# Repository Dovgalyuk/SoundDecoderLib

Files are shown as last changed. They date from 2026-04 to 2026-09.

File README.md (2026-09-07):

# Maple RailRoad Sound Decoder

WiFi controller, sound decoder, and sound projects for model trains.

Project includes library for programming the sounds with set of state machines.

There are several ready-to-use sample sound projects.

Web interface for locomotive operation

Render of the PCB

# Project structure

* esp32 - directory where building of the firmware starts
* hardware - several versions of PCBs for manufacturing the decoder
* projects - ready-to-use sound projects for different locomotives
* compiler - compiler for the sound projects
* emulator - cab emulator for listening sounds with virtual locomotive control
* sample - dummy player which generates wav file by interpreting the sound project
* other directories include the source code of the firmware

# Bringing locomotive to life

* Get the hardware (order PCB, solder the components)
* Build firmware
  * Install ESP32 toolkit (esp idf)
  * Run esp32/build32M.sh (or other version)
* Upload esp32/build32M/esp32sounddecoder.bin into the ESP32 module
* Build selected sound project with compiler/compiler.py
* Upload built project through the web interface into the controller
* Install the controller into the locomotive

# Software features

Controller provides web interface that may be accessed through
WiFi (default address 192.168.4.1).

Sound module plays 8- or 16-bit sounds in 8 channels.

Output functions and sound schemes are programmed with
custom language. The scripts may include conditions,
loops, and finite state machines. These features
may be used for creating complex sound projects.

# Hardware

Controller is intended to be used with G-scale locomotives
with lithium batteries installed, but it may also be used
with track power (some power capacitors are probably needed).

Controller includes the following hardware components:
* ESP32 CPU with embedded WiFi module and flash memory
* Motor driver
* I2S audio power amplifier (MAX98357A)
* 7 programmable outputs
* BEMF for adjusting the motor speed (work in progress)

# Roadmap

* BEMF with new motor driver
* Support of logical input/outputs
* H0-compatible PCB

# Links

* Radio-controlled engines with sound
  - https://github.com/TheDIYGuy999/Rc_Engine_Sound_ESP32
* Cost effective DIY DCC Decoder for model railroad locomotives
  - https://github.com/gab-k/RP2040-Decoder
* NIMRS: open-source NIMRS-21Pin-Decoder, based on the ESP32-S3 microcontroller
  - https://github.com/CDFER/NIMRS-21Pin-Decoder
  - https://github.com/ProjectInitiative/NIMRS-Firmware

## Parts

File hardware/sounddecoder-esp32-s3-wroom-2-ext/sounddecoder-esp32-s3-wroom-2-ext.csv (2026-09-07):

Reference | Qty | Value | DNP | Exclude from BOM | Exclude from Board | Footprint | Datasheet
C1,C3,C8,C10 | 4 | 0.1uF |  |  |  | Capacitor_SMD:C_0805_2012Metric_Pad1.18x1.45mm_HandSolder | ~
C2 | 1 | 47uF |  |  |  | Capacitor_SMD:CP_Elec_6.3x5.4 | ~
C4 | 1 | 470uF |  |  |  | Capacitor_SMD:CP_Elec_10x10.5 | ~
C5 | 1 | 220uF |  |  |  | Capacitor_SMD:C_Elec_6.3x7.7 | ~
C6 | 1 | 22uF |  |  |  | Capacitor_SMD:CP_Elec_4x5.4 | ~
C7 | 1 | 10uF |  |  |  | Capacitor_SMD:C_0805_2012Metric_Pad1.18x1.45mm_HandSolder | ~
C11 | 1 | 22uF |  |  |  | Capacitor_SMD:C_0805_2012Metric_Pad1.18x1.45mm_HandSolder | ~
C12 | 1 | 1uF |  |  |  | Capacitor_SMD:C_0805_2012Metric_Pad1.18x1.45mm_HandSolder | ~
D1 | 1 | SS54 |  |  |  | Diode_SMD:D_SMC | http://www.vishay.com/docs/88526/1n5820.pdf
J1 | 1 | Input power |  |  |  | TerminalBlock:TerminalBlock_Xinya_XY308-2.54-2P_1x02_P2.54mm_Horizontal | ~
J2 | 1 | Extension |  |  |  | Connector_PinHeader_1.27mm:PinHeader_2x08_P1.27mm_Vertical_SMD | ~
J3 | 1 | Motor |  |  |  | TerminalBlock:TerminalBlock_Xinya_XY308-2.54-2P_1x02_P2.54mm_Horizontal | ~
J4 | 1 | Speaker |  |  |  | TerminalBlock:TerminalBlock_Xinya_XY308-2.54-2P_1x02_P2.54mm_Horizontal | ~
J6 | 1 | Conn_01x03_Pin |  |  |  | Connector_PinHeader_1.00mm:PinHeader_1x03_P1.00mm_Vertical | ~
J7 | 1 | Smoke |  |  |  | TerminalBlock:TerminalBlock_Xinya_XY308-2.54-2P_1x02_P2.54mm_Horizontal | ~
J8 | 1 | FwdLED |  |  |  | TerminalBlock:TerminalBlock_Xinya_XY308-2.54-2P_1x02_P2.54mm_Horizontal | ~
J9 | 1 | BackLED |  |  |  | TerminalBlock:TerminalBlock_Xinya_XY308-2.54-2P_1x02_P2.54mm_Horizontal | ~
J10 | 1 | AUX1 |  |  |  | TerminalBlock:TerminalBlock_Xinya_XY308-2.54-2P_1x02_P2.54mm_Horizontal | ~
J11 | 1 | AUX2 |  |  |  | TerminalBlock:TerminalBlock_Xinya_XY308-2.54-2P_1x02_P2.54mm_Horizontal | ~
J12 | 1 | AUX3 |  |  |  | TerminalBlock:TerminalBlock_Xinya_XY308-2.54-2P_1x02_P2.54mm_Horizontal | ~
J13 | 1 | AUX4 |  |  |  | TerminalBlock:TerminalBlock_Xinya_XY308-2.54-2P_1x02_P2.54mm_Horizontal | ~
L1 | 1 | 47uh/L39 |  |  |  | Inductor_SMD:L_Bourns_SRP1245A | ~
R1,R6,R7 | 3 | 1k |  |  |  | Resistor_SMD:R_0805_2012Metric_Pad1.20x1.40mm_HandSolder | ~
R2,R3 | 2 | 10k |  |  |  | Resistor_SMD:R_0805_2012Metric_Pad1.20x1.40mm_HandSolder | ~
R4,R5 | 2 | 20k |  |  |  | Resistor_SMD:R_0805_2012Metric_Pad1.20x1.40mm_HandSolder | ~
U1 | 1 | LM2596S-5 |  |  |  | Package_TO_SOT_SMD:TO-263-5_TabPin3 | http://www.ti.com/lit/ds/symlink/lm2596.pdf
U3 | 1 | MAX98357A |  |  |  | Package_DFN_QFN:TQFN-16-1EP_3x3mm_P0.5mm_EP1.23x1.23mm | https://www.analog.com/media/en/technical-documentation/data-sheets/MAX98357A-MAX98357B.pdf
U4 | 1 | DRV8251A |  |  |  | Package_SO:Texas_HSOP-8-1EP_3.9x4.9mm_P1.27mm_ThermalVias
U6 | 1 | AMS1117-3.3 |  |  |  | Package_TO_SOT_SMD:SOT-223-3_TabPin2 | http://www.advanced-monolithic.com/pdf/ds1117.pdf
U7 | 1 | ESP32-S3-WROOM-2 |  |  |  | RF_Module:ESP32-S3-WROOM-2 | https://www.espressif.com/sites/default/files/documentation/esp32-s3-wroom-2_datasheet_en.pdf
U8 | 1 | ULN2003A |  |  |  | Package_SO:SO-16_3.9x9.9mm_P1.27mm | http://www.ti.com/lit/ds/symlink/uln2003a.pdf

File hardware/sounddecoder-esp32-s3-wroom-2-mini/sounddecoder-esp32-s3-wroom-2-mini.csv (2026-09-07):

Reference | Qty | Value | DNP | Exclude from BOM | Exclude from Board | Footprint | Datasheet
C1,C3,C8,C10 | 4 | 0.1uF |  |  |  | Capacitor_SMD:C_0805_2012Metric | ~
C4 | 1 | 470uF |  |  |  | Capacitor_SMD:CP_Elec_10x10.5 | ~
C5 | 1 | 220uF |  |  |  | Capacitor_SMD:C_Elec_6.3x7.7 | ~
C6 | 1 | 22uF |  |  |  | Capacitor_SMD:CP_Elec_4x5.4 | ~
C7 | 1 | 10uF |  |  |  | Capacitor_SMD:C_0805_2012Metric | ~
C11 | 1 | 22uF |  |  |  | Capacitor_SMD:C_0805_2012Metric | ~
C12 | 1 | 1uF |  |  |  | Capacitor_SMD:C_0805_2012Metric | ~
D1 | 1 | SS54 |  |  |  | Diode_SMD:D_SMC | http://www.vishay.com/docs/88526/1n5820.pdf
J1 | 1 | Input power |  |  |  | TerminalBlock:TerminalBlock_Xinya_XY308-2.54-2P_1x02_P2.54mm_Horizontal | ~
J2 | 1 | Conn_01x02_Pin |  |  |  | Connector_PinHeader_1.00mm:PinHeader_1x02_P1.00mm_Vertical | ~
J3 | 1 | Motor |  |  |  | TerminalBlock:TerminalBlock_Xinya_XY308-2.54-2P_1x02_P2.54mm_Horizontal | ~
J4 | 1 | Speaker |  |  |  | Connector_PinHeader_2.54mm:PinHeader_1x02_P2.54mm_Vertical | ~
J8 | 1 | FwdLED |  |  |  | Connector_PinHeader_2.54mm:PinHeader_1x02_P2.54mm_Vertical | ~
J9 | 1 | BackLED |  |  |  | Connector_PinHeader_2.54mm:PinHeader_1x02_P2.54mm_Vertical | ~
J10 | 1 | AUX1 |  |  |  | Connector_PinHeader_2.54mm:PinHeader_1x02_P2.54mm_Vertical | ~
J11 | 1 | AUX2 |  |  |  | Connector_PinHeader_2.54mm:PinHeader_1x02_P2.54mm_Vertical | ~
J101 | 1 | Conn_01x05 |  |  |  | Connector_PinHeader_2.54mm:PinHeader_1x05_P2.54mm_Vertical | ~
L1 | 1 | 47uh/L39 |  |  |  | Inductor_SMD:L_Bourns_SRP1245A | ~
R1,R6,R7 | 3 | 1k |  |  |  | Resistor_SMD:R_0805_2012Metric | ~
R2,R3 | 2 | 10k |  |  |  | Resistor_SMD:R_0805_2012Metric | ~
R4,R5 | 2 | 20k |  |  |  | Resistor_SMD:R_0805_2012Metric | ~
U1 | 1 | LM2596S-5 |  |  |  | Package_TO_SOT_SMD:TO-263-5_TabPin3 | http://www.ti.com/lit/ds/symlink/lm2596.pdf
U3 | 1 | MAX98357A |  |  |  | Package_DFN_QFN:TQFN-16-1EP_3x3mm_P0.5mm_EP1.23x1.23mm | https://www.analog.com/media/en/technical-documentation/data-sheets/MAX98357A-MAX98357B.pdf
U4 | 1 | DRV8251A |  |  |  | Package_SO:Texas_HSOP-8-1EP_3.9x4.9mm_P1.27mm_ThermalVias
U6 | 1 | AMS1117-3.3 |  |  |  | Package_TO_SOT_SMD:SOT-223-3_TabPin2 | http://www.advanced-monolithic.com/pdf/ds1117.pdf
U7 | 1 | ESP32-S3-WROOM-2 |  |  |  | RF_Module:ESP32-S3-WROOM-2 | https://www.espressif.com/sites/default/files/documentation/esp32-s3-wroom-2_datasheet_en.pdf
U8 | 1 | ULN2003A |  |  |  | Package_SO:SO-16_3.9x9.9mm_P1.27mm | http://www.ti.com/lit/ds/symlink/uln2003a.pdf

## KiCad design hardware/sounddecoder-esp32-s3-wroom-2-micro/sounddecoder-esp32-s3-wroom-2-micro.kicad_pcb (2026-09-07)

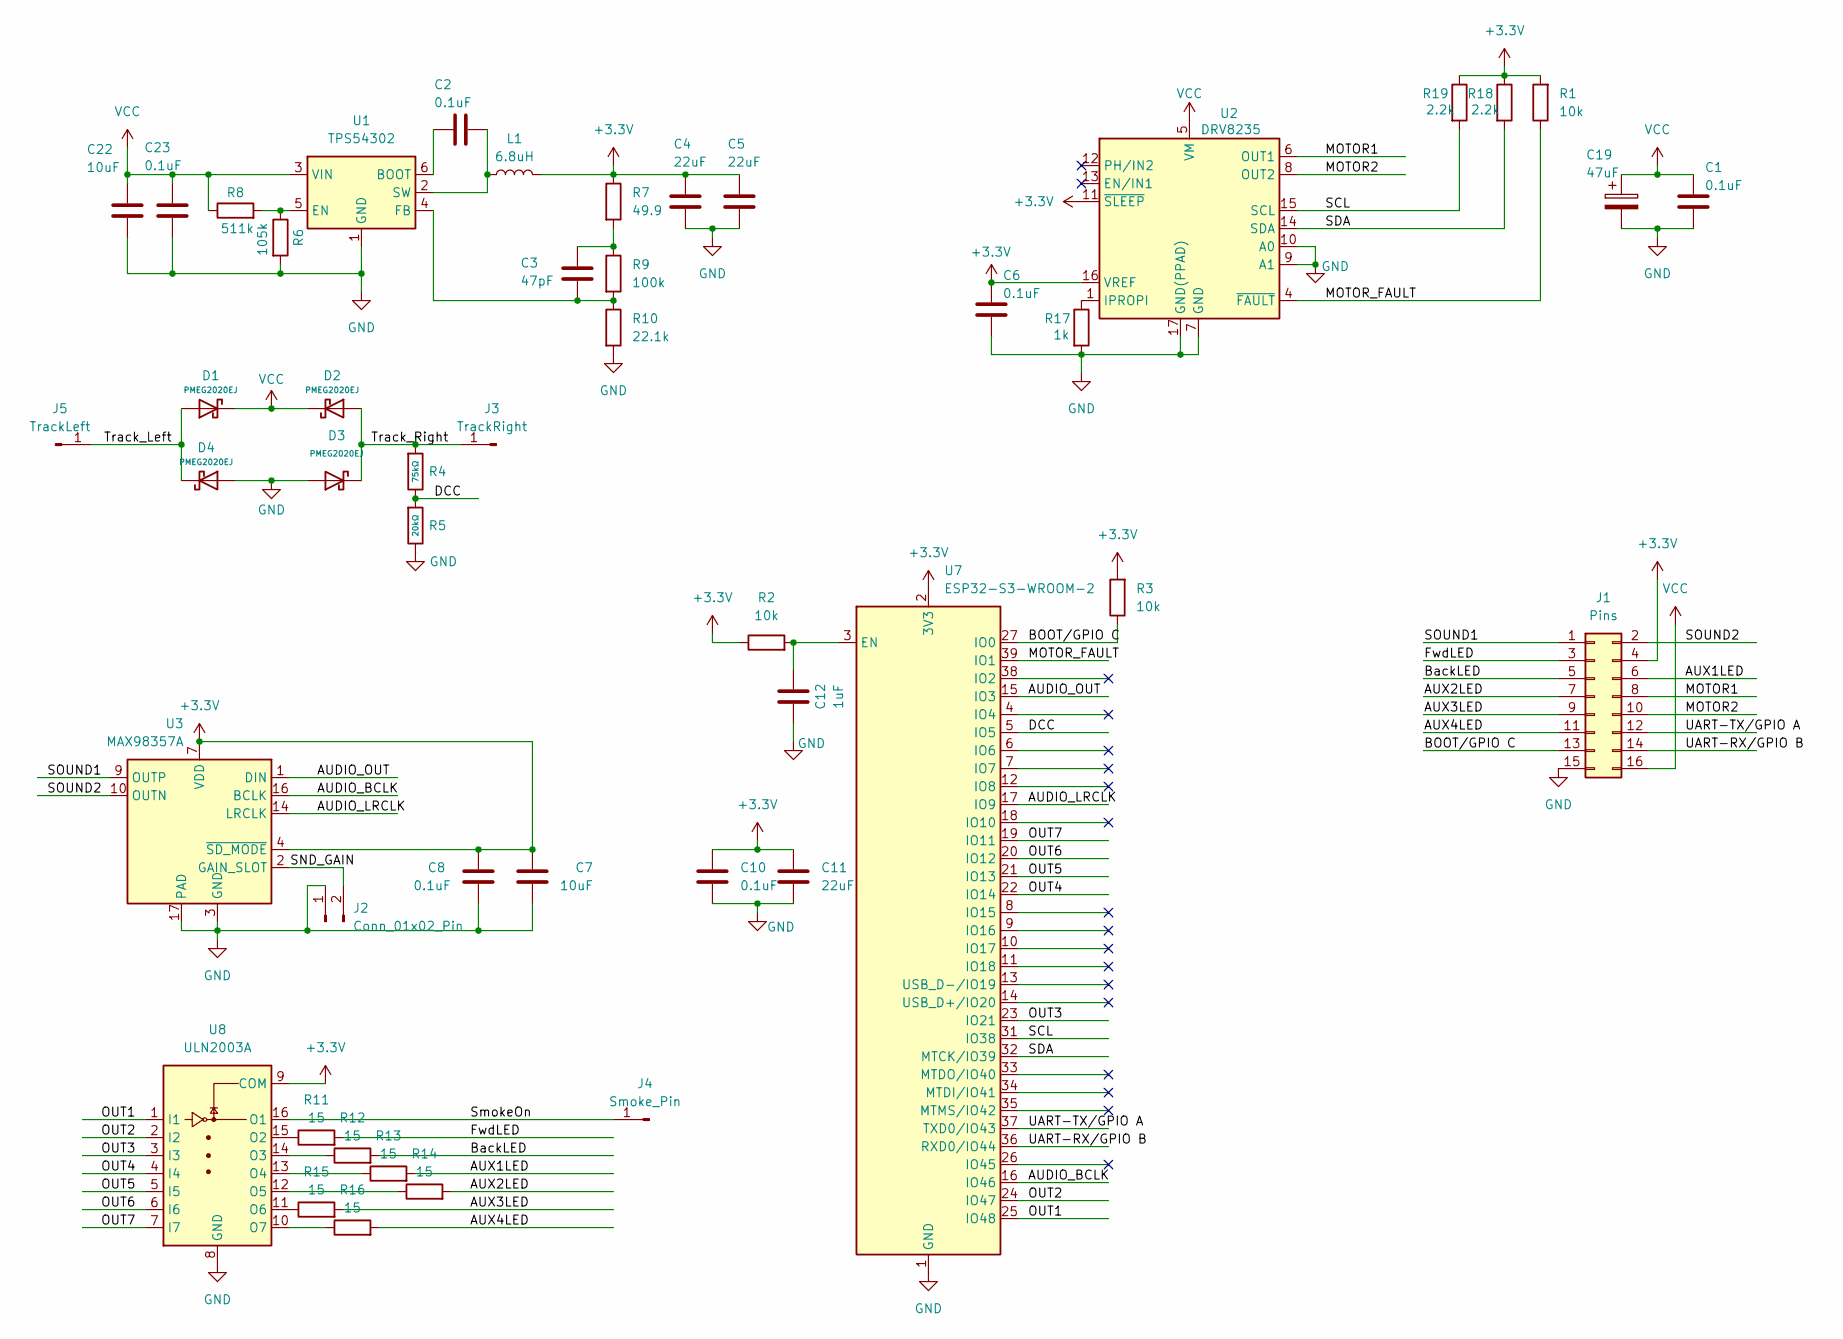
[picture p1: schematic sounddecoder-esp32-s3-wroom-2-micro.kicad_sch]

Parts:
C1, C2, C6, C8, C10, C23: 0.1uF; C_0603_1608Metric
C3: 47pF; C_0603_1608Metric
C4, C5, C11: 22uF; C_0603_1608Metric
C7, C22: 10uF; C_0603_1608Metric
C12: 1uF; C_0603_1608Metric
C19: 47uF; CP_Elec_6.3x5.4
D1, D2, D3, D4: PMEG2020EJ; D_SOD-323; Forward Voltage (Vf@If) 450mV@1.0A; Reverse Voltage (Vr) 20V; Part B5817WS; LCSC C7420329
J1: Pins; PinHeader_2x08_P2.00mm_Vertical
J2: Conn_01x02_Pin; SolderJumper-2_P1.3mm_Open_RoundedPad1.0x1.5mm
J3: TrackRight; TestPoint_THTPad_1.0x1.0mm_Drill0.5mm
J4: Smoke_Pin; TestPoint_THTPad_1.0x1.0mm_Drill0.5mm
J5: TrackLeft; TestPoint_THTPad_1.0x1.0mm_Drill0.5mm
L1: 6.8uH; L_Chilisin_BMRA00050530
R1, R2, R3: 10k; C_0603_1608Metric
R4: 75kΩ; C_0603_1608Metric; Overload Voltage (Max) 50V; Tolerance ±1%; Part 0402WGF7502TCE; LCSC C25798
R5: 20kΩ; C_0603_1608Metric; Overload Voltage (Max) 50V; Tolerance ±1%; Part 0402WGF2002TCE; LCSC C25765
R6: 105k; C_0603_1608Metric
R7: 49.9; C_0603_1608Metric
R8: 511k; C_0603_1608Metric
R9: 100k; C_0603_1608Metric
R10: 22.1k; C_0603_1608Metric
R11, R12, R13, R14, R15, R16: 15; C_0603_1608Metric
R17: 1k; C_0603_1608Metric
R18, R19: 2.2k; C_0603_1608Metric
U1: TPS54302; SOT-23-6
U2: DRV8235; WQFN-16-1EP_3x3mm_P0.5mm_EP1.68x1.68mm_ThermalVias
U3: MAX98357A; TQFN-16-1EP_3x3mm_P0.5mm_EP1.23x1.23mm
U7: ESP32-S3-WROOM-2
U8: ULN2003A; SO-16_3.9x9.9mm_P1.27mm

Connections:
+3.3V: C4.1, C5.1, C6.1, C7.1, C8.1, C10.1, C11.1, J1.4, L1.2, R1.2, R2.1, R3.2, R7.1, R18.1, R19.1, U2.11 (~SLEEP), U2.16 (VREF), U3.4 (~SD_MODE), U3.7 (VDD), U3.8 (VDD), U7.2 (3V3), U8.9 (COM)
/AUDIO_BCLK: U3.16 (BCLK), U7.16 (IO46)
/AUDIO_LRCLK: U3.14 (LRCLK), U7.17 (IO9)
/AUDIO_OUT: U3.1 (DIN), U7.15 (IO3)
/AUX1LED: J1.6, R13.2
/AUX2LED: J1.7, R14.2
/AUX3LED: J1.9, R15.2
/AUX4LED: J1.11, R16.2
/BOOT/GPIO C: J1.13, R3.1, U7.27 (IO0)
/BackLED: J1.5, R12.2
/DCC: R4.2, R5.1, U7.5 (IO5)
/FwdLED: J1.3, R11.2
/MOTOR1: J1.8, U2.6 (OUT1)
/MOTOR2: J1.10, U2.8 (OUT2)
/MOTOR_FAULT: R1.1, U2.4 (~FAULT), U7.39 (IO1)
/OUT1: U7.25 (IO48), U8.1 (I1)
/OUT2: U7.24 (IO47), U8.2 (I2)
/OUT3: U7.23 (IO21), U8.3 (I3)
/OUT4: U7.22 (IO14), U8.4 (I4)
/OUT5: U7.21 (IO13), U8.5 (I5)
/OUT6: U7.20 (IO12), U8.6 (I6)
/OUT7: U7.19 (IO11), U8.7 (I7)
/SCL: R19.2, U2.15 (SCL), U7.31 (IO38)
/SDA: R18.2, U2.14 (SDA), U7.32 (MTCK/IO39)
/SND_GAIN: J2.2, U3.2 (GAIN_SLOT)
/SOUND1: J1.1, U3.9 (OUTP)
/SOUND2: J1.2, U3.10 (OUTN)
/SmokeOn: J4.1, U8.16 (O1)
/Track_Left: D1.2, D4.1, J5.1
/Track_Right: D2.2, D3.1, J3.1, R4.1
/UART-RX/GPIO B: J1.14, U7.36 (RXD0/IO44)
/UART-TX/GPIO A: J1.12, U7.37 (TXD0/IO43)
GND: C1.2, C4.2, C5.2, C6.2, C7.2, C8.2, C10.2, C11.2, C12.1, C19.2, C22.2, C23.2, D3.2, D4.2, J1.15, J2.1, R5.2, R6.2, R10.2, R17.2, U1.1 (GND), U2.7 (GND), U2.9 (A1), U2.10 (A0), U2.17 (GND(PPAD)), U3.3 (GND), U3.11 (GND), U3.15 (GND), U3.17 (PAD), U7.1 (GND), U7.40 (GND), U7.41 (GND), U8.8 (GND)
unnamed: C3.1, R7.2, R9.1
unnamed: C2.1, U1.6 (BOOT)
unnamed: R6.1, R8.2, U1.5 (EN)
unnamed: C3.2, R9.2, R10.1, U1.4 (FB)
unnamed: C2.2, L1.1, U1.2 (SW)
unnamed: R17.1, U2.1 (IPROPI)
unnamed: C12.2, R2.2, U7.3 (EN)
unnamed: R11.1, U8.15 (O2)
unnamed: R12.1, U8.14 (O3)
unnamed: R13.1, U8.13 (O4)
unnamed: R14.1, U8.12 (O5)
unnamed: R15.1, U8.11 (O6)
unnamed: R16.1, U8.10 (O7)
VCC: C1.1, C19.1, C22.1, C23.1, D1.1, D2.1, J1.16, R8.1, U1.3 (VIN), U2.5 (VM)

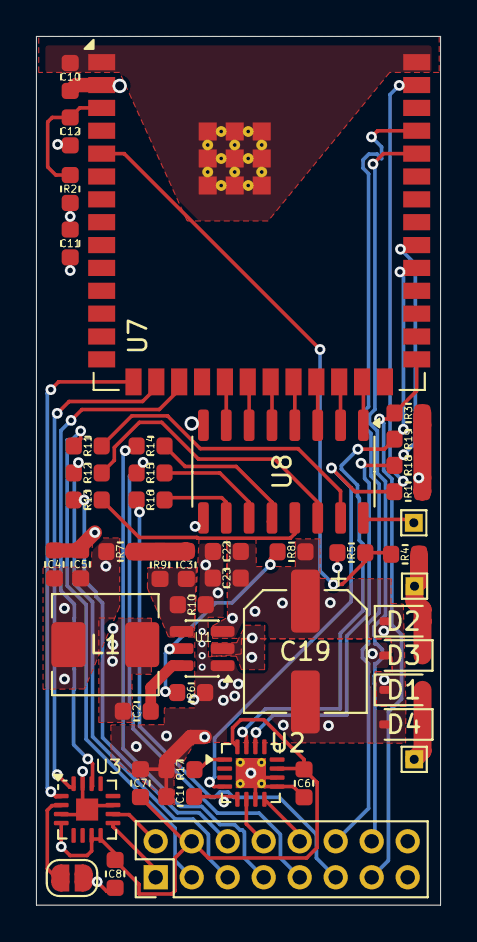
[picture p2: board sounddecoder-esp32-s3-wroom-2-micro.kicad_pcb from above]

Board: 4 copper layers, 22.5 x 48.3 mm, 48 parts (0 on the bottom side), 47 nets.

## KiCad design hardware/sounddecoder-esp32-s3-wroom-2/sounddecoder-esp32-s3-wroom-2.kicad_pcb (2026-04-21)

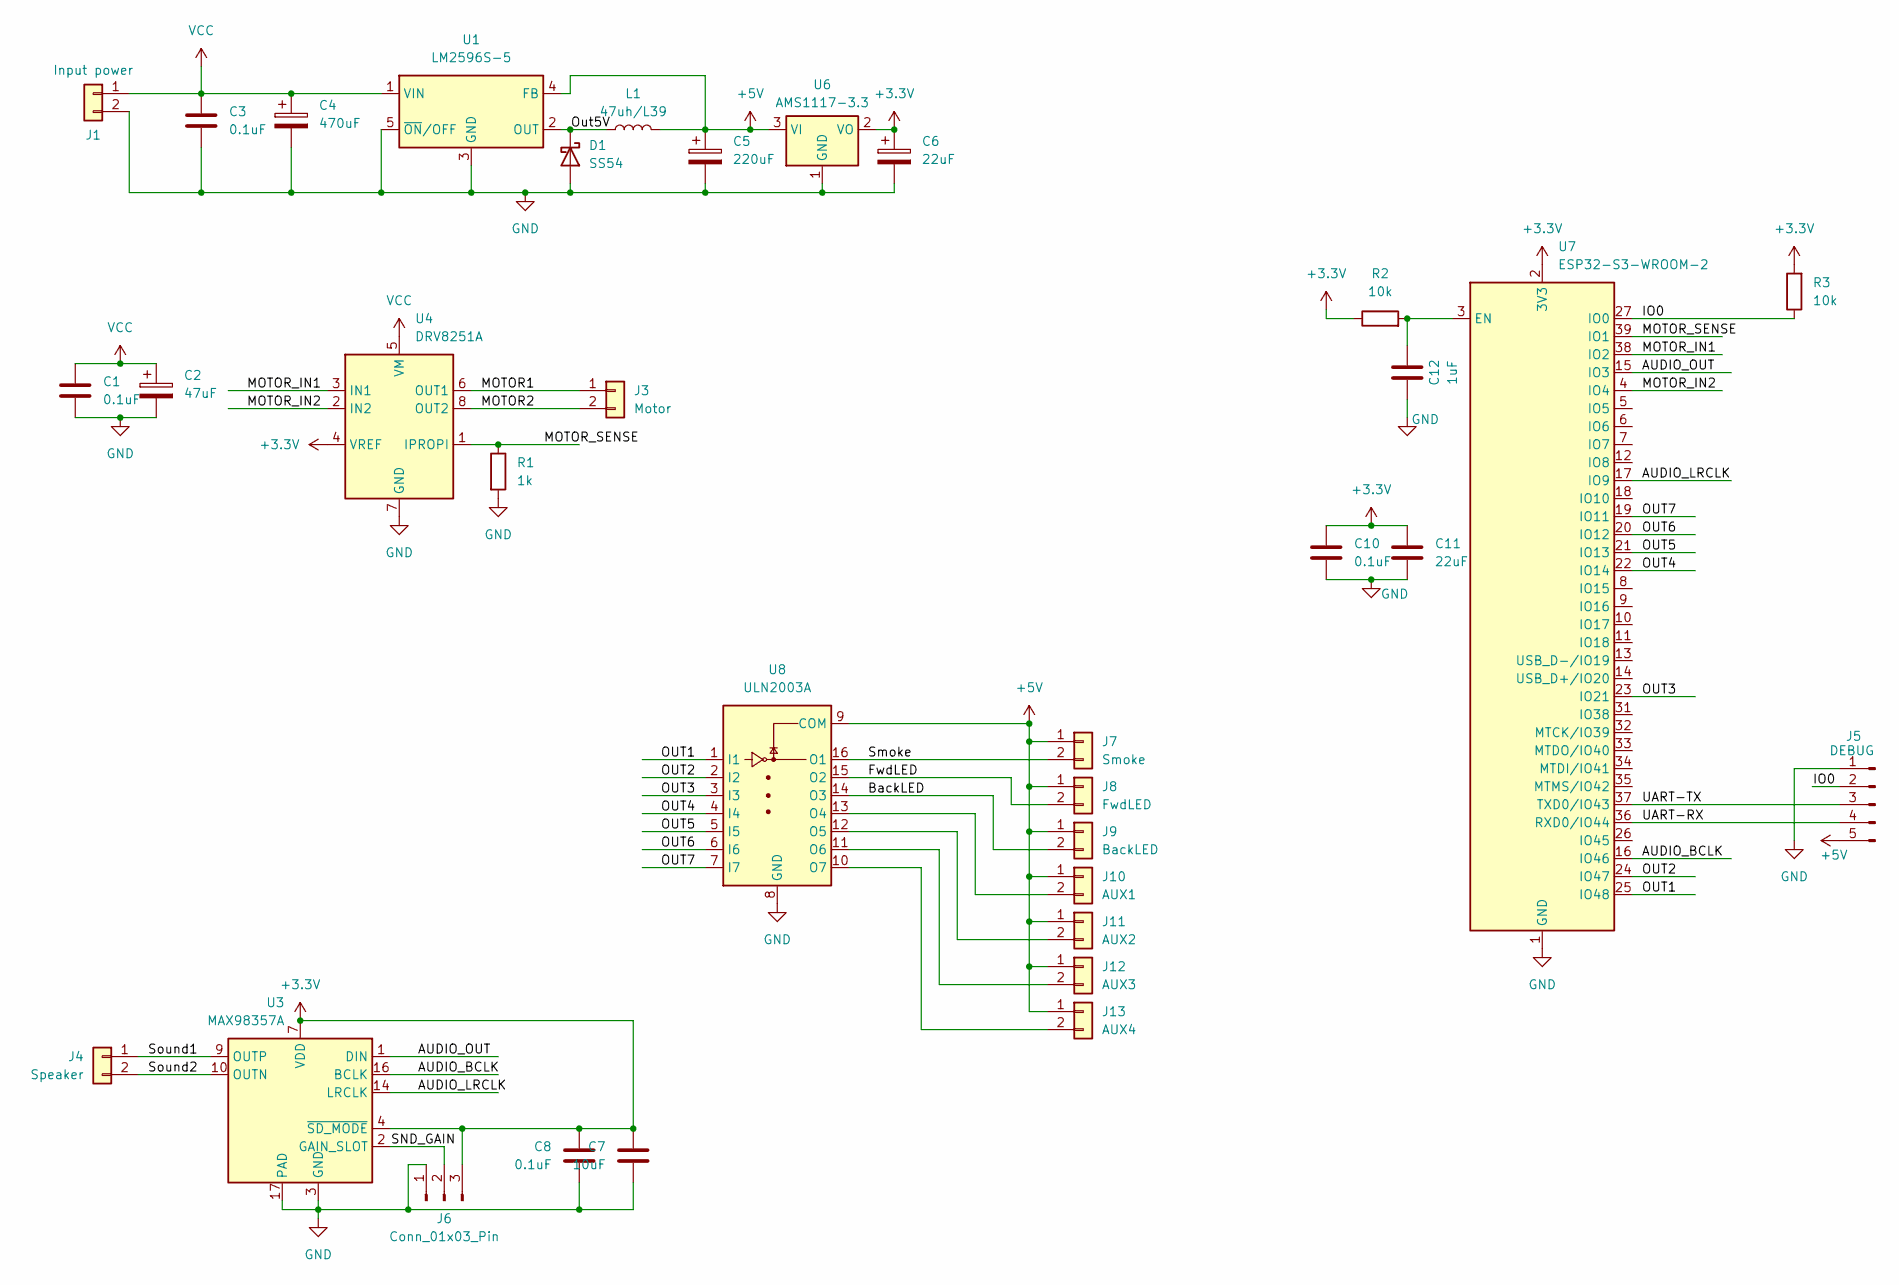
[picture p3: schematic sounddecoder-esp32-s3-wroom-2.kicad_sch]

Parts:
C1, C3, C8, C10: 0.1uF; C_0805_2012Metric_Pad1.18x1.45mm_HandSolder
C2: 47uF; CP_Elec_6.3x5.4
C4: 470uF; CP_Elec_10x10.5
C5: 220uF; C_Elec_6.3x7.7
C6: 22uF; CP_Elec_4x5.4
C7: 10uF; C_0805_2012Metric_Pad1.18x1.45mm_HandSolder
C11: 22uF; C_0805_2012Metric_Pad1.18x1.45mm_HandSolder
C12: 1uF; C_0805_2012Metric_Pad1.18x1.45mm_HandSolder
D1: SS54; D_SMC
J1: Input power; TerminalBlock_Xinya_XY308-2.54-2P_1x02_P2.54mm_Horizontal
J3: Motor; TerminalBlock_Xinya_XY308-2.54-2P_1x02_P2.54mm_Horizontal
J4: Speaker; TerminalBlock_Xinya_XY308-2.54-2P_1x02_P2.54mm_Horizontal
J5: DEBUG; PinHeader_1x05_P2.54mm_Horizontal
J6: Conn_01x03_Pin; PinHeader_1x03_P1.00mm_Vertical
J7: Smoke; TerminalBlock_Xinya_XY308-2.54-2P_1x02_P2.54mm_Horizontal
J8: FwdLED; TerminalBlock_Xinya_XY308-2.54-2P_1x02_P2.54mm_Horizontal
J9: BackLED; TerminalBlock_Xinya_XY308-2.54-2P_1x02_P2.54mm_Horizontal
J10: AUX1; TerminalBlock_Xinya_XY308-2.54-2P_1x02_P2.54mm_Horizontal
J11: AUX2; TerminalBlock_Xinya_XY308-2.54-2P_1x02_P2.54mm_Horizontal
J12: AUX3; TerminalBlock_Xinya_XY308-2.54-2P_1x02_P2.54mm_Horizontal
J13: AUX4; TerminalBlock_Xinya_XY308-2.54-2P_1x02_P2.54mm_Horizontal
L1: 47uh/L39; L_Bourns_SRP1245A
R1: 1k; R_0805_2012Metric_Pad1.20x1.40mm_HandSolder
R2, R3: 10k; R_0805_2012Metric_Pad1.20x1.40mm_HandSolder
U1: LM2596S-5; TO-263-5_TabPin3
U3: MAX98357A; TQFN-16-1EP_3x3mm_P0.5mm_EP1.23x1.23mm
U4: DRV8251A; Texas_HSOP-8-1EP_3.9x4.9mm_P1.27mm_ThermalVias
U6: AMS1117-3.3; SOT-223-3_TabPin2
U7: ESP32-S3-WROOM-2
U8: ULN2003A; SO-16_3.9x9.9mm_P1.27mm

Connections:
+3.3V: C6.1, C7.1, C8.1, C10.1, C11.1, J6.3, R2.1, R3.2, U3.4 (~SD_MODE), U3.7 (VDD), U3.8 (VDD), U4.4 (VREF), U6.2 (VO), U7.2 (3V3)
+5V: C5.1, J5.5, J7.1, J8.1, J9.1, J10.1, J11.1, J12.1, J13.1, L1.2, U1.4 (FB), U6.3 (VI), U8.9 (COM)
/AUDIO_BCLK: U3.16 (BCLK), U7.16 (IO46)
/AUDIO_LRCLK: U3.14 (LRCLK), U7.17 (IO9)
/AUDIO_OUT: U3.1 (DIN), U7.15 (IO3)
/BackLED: J9.2, U8.14 (O3)
/FwdLED: J8.2, U8.15 (O2)
/IO0: J5.2, R3.1, U7.27 (IO0)
/MOTOR1: J3.1, U4.6 (OUT1)
/MOTOR2: J3.2, U4.8 (OUT2)
/MOTOR_IN1: U4.3 (IN1), U7.38 (IO2)
/MOTOR_IN2: U4.2 (IN2), U7.4 (IO4)
/MOTOR_SENSE: R1.1, U4.1 (IPROPI), U7.39 (IO1)
/OUT1: U7.25 (IO48), U8.1 (I1)
/OUT2: U7.24 (IO47), U8.2 (I2)
/OUT3: U7.23 (IO21), U8.3 (I3)
/OUT4: U7.22 (IO14), U8.4 (I4)
/OUT5: U7.21 (IO13), U8.5 (I5)
/OUT6: U7.20 (IO12), U8.6 (I6)
/OUT7: U7.19 (IO11), U8.7 (I7)
/Out5V: D1.1 (K), L1.1, U1.2 (OUT)
/SND_GAIN: J6.2, U3.2 (GAIN_SLOT)
/Smoke: J7.2, U8.16 (O1)
/Sound1: J4.1, U3.9 (OUTP)
/Sound2: J4.2, U3.10 (OUTN)
/UART-RX: J5.4, U7.36 (RXD0/IO44)
/UART-TX: J5.3, U7.37 (TXD0/IO43)
GND: C1.2, C2.2, C3.2, C4.2, C5.2, C6.2, C7.2, C8.2, C10.2, C11.2, C12.1, D1.2 (A), J1.2, J5.1, J6.1, R1.2, U1.3 (GND), U1.5 (~ON/OFF), U3.3 (GND), U3.11 (GND), U3.15 (GND), U3.17 (PAD), U4.7 (GND), U4.9 (GND), U6.1 (GND), U7.1 (GND), U7.40 (GND), U7.41 (GND), U8.8 (GND)
unnamed: J10.2, U8.13 (O4)
unnamed: J11.2, U8.12 (O5)
unnamed: J12.2, U8.11 (O6)
unnamed: J13.2, U8.10 (O7)
unnamed: C12.2, R2.2, U7.3 (EN)
VCC: C1.1, C2.1, C3.1, C4.1, J1.1, U1.1 (VIN), U4.5 (VM)

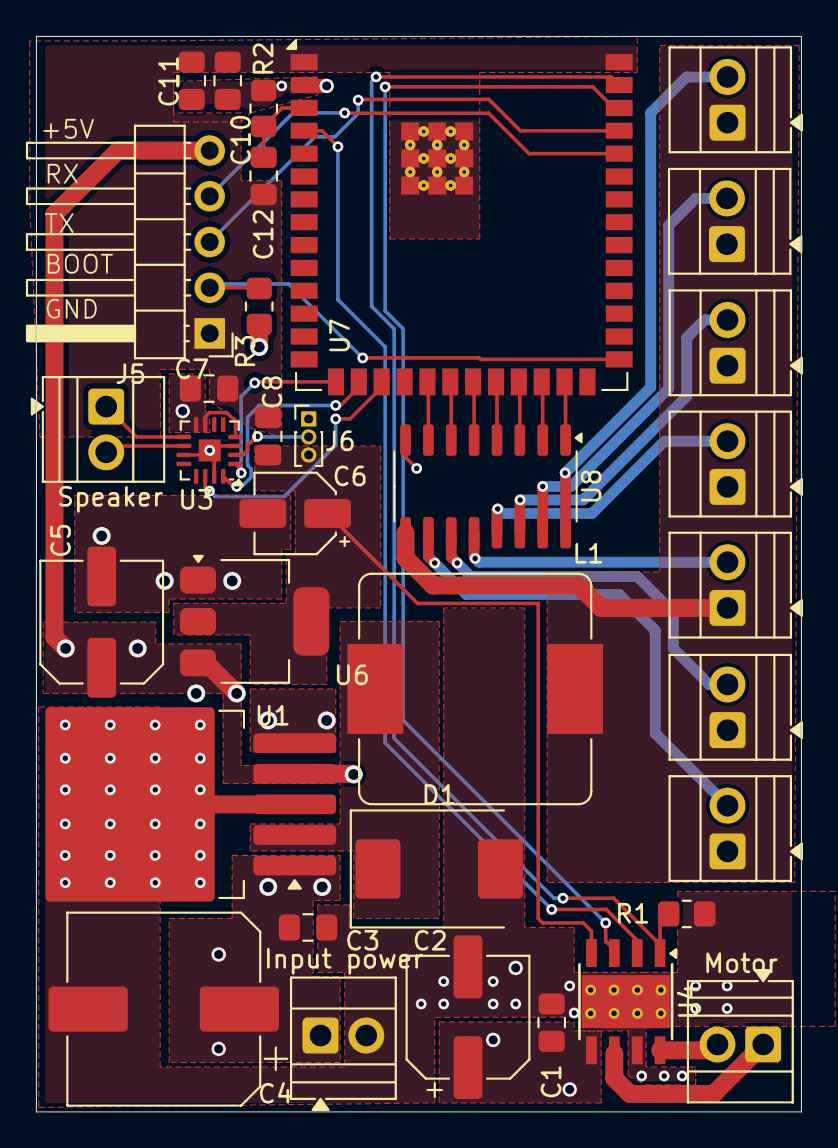
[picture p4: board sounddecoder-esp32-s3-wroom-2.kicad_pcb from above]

Board: 4 copper layers, 42.5 x 59.8 mm, 34 parts (0 on the bottom side), 34 nets.

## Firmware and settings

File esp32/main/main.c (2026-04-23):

#include <stdio.h>
#include <inttypes.h>
#include "sdkconfig.h"
#include "freertos/FreeRTOS.h"
#include "freertos/task.h"
#include "esp_chip_info.h"
#include "esp_flash.h"
#include "esp_system.h"
#include "esp_timer.h"
#include "esp_log.h"
/* Components */
#include "wifi.h"
#include "web.h"
#include "storage.h"
/* Decoder VM */
#include "schedule.h"
#include "slot.h"
#include "variables.h"
#include "vm.h"
#include "player.h"
#include "audio.h"
#include "engine.h"
#include "project.h"
#include "cv.h"
#include "logger.h"

#define TAG "main"

static uint64_t clock_read_ms(void)
{
    return esp_timer_get_time() / 1000;
}

static void vm_task(void *args)
{
    uint64_t last_clock = clock_read_ms();
    while (true) {
        uint64_t cur_clock = clock_read_ms();
        uint32_t t = cur_clock - last_clock;
        last_clock = cur_clock;
        project_tick(t);
        engine_tick(t);
        vm_tick(t);
        vTaskDelay(pdMS_TO_TICKS(10));
    }
}

void app_main(void)
{
    /* Print chip information */
    esp_chip_info_t chip_info;
    uint32_t flash_size;
    esp_chip_info(&chip_info);
    printf("This is %s chip with %d CPU core(s), %s%s%s%s, ",
           CONFIG_IDF_TARGET,
           chip_info.cores,
           (chip_info.features & CHIP_FEATURE_WIFI_BGN) ? "WiFi/" : "",
           (chip_info.features & CHIP_FEATURE_BT) ? "BT" : "",
           (chip_info.features & CHIP_FEATURE_BLE) ? "BLE" : "",
           (chip_info.features & CHIP_FEATURE_IEEE802154) ? ", 802.15.4 (Zigbee/Thread)" : "");

    unsigned major_rev = chip_info.revision / 100;
    unsigned minor_rev = chip_info.revision % 100;
    printf("silicon revision v%d.%d, ", major_rev, minor_rev);
    if(esp_flash_get_size(NULL, &flash_size) != ESP_OK) {
        printf("Get flash size failed");
        return;
    }

    logger_printf("%" PRIu32 "MB %s flash", flash_size / (uint32_t)(1024 * 1024),
           (chip_info.features & CHIP_FEATURE_EMB_FLASH) ? "embedded" : "external");

    logger_printf("Free heap size: %" PRIu32 " bytes", esp_get_free_heap_size());

    /* Init default CVs at start */
    cv_init();
    wifi_init();
    web_init();
    storage_init();
    project_open();
    /* Load CVs after opening the project */
    cv_storage_init();
    vm_init_function_keys();
    player_init();
    engine_init();

    logger_printf("Free heap size after init: %" PRIu32 " bytes", esp_get_free_heap_size());

    xTaskCreatePinnedToCore(vm_task, "vm_task", 5120, NULL, 5, NULL, 0);
}

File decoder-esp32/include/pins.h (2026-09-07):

#ifndef PINS_H
#define PINS_H

#include "sdkconfig.h"

#if CONFIG_IDF_TARGET_ESP32S3
/* Sound */
#   if CONFIG_BOARD_VERSION==1
#       define I2S_BCLK_IO1         12
#       define I2S_WS_IO1           13
#       define I2S_DOUT_IO1         11
#   elif CONFIG_BOARD_VERSION>=2
#       define I2S_BCLK_IO1         46
#       define I2S_WS_IO1           9
#       define I2S_DOUT_IO1         3
#   endif
/* Motor */
#   if CONFIG_BOARD_VERSION==2
#       define MOTOR_INPUT_V        1
#       define MOTOR_ADC_UNIT       ADC_UNIT_1
#       define MOTOR_ADC_CHANNEL    ADC_CHANNEL_0
#   elif CONFIG_BOARD_VERSION==3
#       define MOTOR_INPUT_FAULT      1
#       define MOTOR_SCL              38
#       define MOTOR_SDA              39
#   endif
#   define MOTOR_OUTPUT_DIR1          2
#   define MOTOR_OUTPUT_DIR2          4
/* Physical outputs */
#   if CONFIG_BOARD_VERSION==1
#       define PHYS_OUTPUT_SMOKE      47
#       define PHYS_OUTPUT_FWD_LIGHT  48
#       define PHYS_OUTPUT_BACK_LIGHT 42
#       define PHYS_OUTPUT_4          41
#       define PHYS_OUTPUT_5          40
#       define PHYS_OUTPUT_6          39
#       define PHYS_OUTPUT_7          38
#   elif CONFIG_BOARD_VERSION>=2
#       define PHYS_OUTPUT_SMOKE      48
#       define PHYS_OUTPUT_FWD_LIGHT  47
#       define PHYS_OUTPUT_BACK_LIGHT 21
#       define PHYS_OUTPUT_4          14
#       define PHYS_OUTPUT_5          13
#       define PHYS_OUTPUT_6          12
#       define PHYS_OUTPUT_7          11
#   endif
/* Storage */
#   if CONFIG_BOARD_VERSION==1
#       define FLASH_SPI_D0         8
#       define FLASH_SPI_D1         15
#       define FLASH_SPI_D2         16
#       define FLASH_SPI_D3         17
#       define FLASH_SPI_CLK        18
#       define FLASH_SPI_CS         7
#   endif
#else
#   error Define pins for peripherals
#endif

#endif

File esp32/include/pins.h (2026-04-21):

#ifndef PINS_H
#define PINS_H

#include "sdkconfig.h"

#if CONFIG_IDF_TARGET_ESP32S3
/* Sound */
#   define I2S_BCLK_IO1         12
#   define I2S_WS_IO1           13
#   define I2S_DOUT_IO1         11
/* Motor */
#   define MOTOR_INPUT_V        1
#   define MOTOR_OUTPUT_DIR1    2
#   define MOTOR_OUTPUT_DIR2    4
/* Physical outputs */
#   define PHYS_OUTPUT_SMOKE      47
#   define PHYS_OUTPUT_FWD_LIGHT  48
#   define PHYS_OUTPUT_BACK_LIGHT 42
/* Storage */
#   define FLASH_SPI_D0         8
#   define FLASH_SPI_D1         15
#   define FLASH_SPI_D2         16
#   define FLASH_SPI_D3         17
#   define FLASH_SPI_CLK        18
#   define FLASH_SPI_CS         7
#else
#   error Define pins for peripherals
#endif

#endif

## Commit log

2026-03-12 Upload datasheets and create schematic stub
    [sounddecoder-esp32-wroom-32d.kicad_pcb, sounddecoder-esp32-wroom-32d.kicad_sch]
2026-03-16 Many updates
    [sounddecoder-esp32-s3-wroom-1.kicad_pcb, sounddecoder-esp32-s3-wroom-1.kicad_sch]
2026-03-23 Created PCB
    [sounddecoder-esp32-s3-wroom-1-B_Cu.gbr, sounddecoder-esp32-s3-wroom-1-B_Mask.gbr, sounddecoder-esp32-s3-wroom-1-B_Paste.gbr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]
2026-04-16 Started working on board v2
    [partitions.csv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]
2026-04-21 Finished v2 board
    [sounddecoder-esp32-s3-wroom-2-B_Cu.gbr, sounddecoder-esp32-s3-wroom-2-B_Mask.gbr, sounddecoder-esp32-s3-wroom-2-B_Paste.gbr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]
2026-09-07 Added support of DRV8235 motor driver
    [sounddecoder-esp32-s3-wroom-2-ext.csv, sounddecoder-esp32-s3-wroom-2-micro.kicad_pcb, sounddecoder-esp32-s3-wroom-2-micro.kicad_sch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]
